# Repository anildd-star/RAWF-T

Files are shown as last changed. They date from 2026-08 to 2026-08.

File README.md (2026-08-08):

# RAF — Silah Organizörü

Three.js önizleme + **Elegoo Centauri Carbon 2** baskı kiti.

## Bugün baskı

1. [`print/BUGUN.md`](print/BUGUN.md) — adım adım  
2. Plakalar: [`print/plates/`](print/plates/) veya [`print/RAF-CC2-PLATES.3mf`](print/RAF-CC2-PLATES.3mf)  
3. **ELEGOO Slicer** → Centauri Carbon 2 → PETG → 5 mm brim → slice

Day-1: 2× panel + `plate_DAY1_minimum` → 2 silah asacak set.

## Tam dokümantasyon

[`print/PRINT_GUIDE.md`](print/PRINT_GUIDE.md)

```bash
python3 scripts/generate_print_kit.py
npx --yes serve .
```

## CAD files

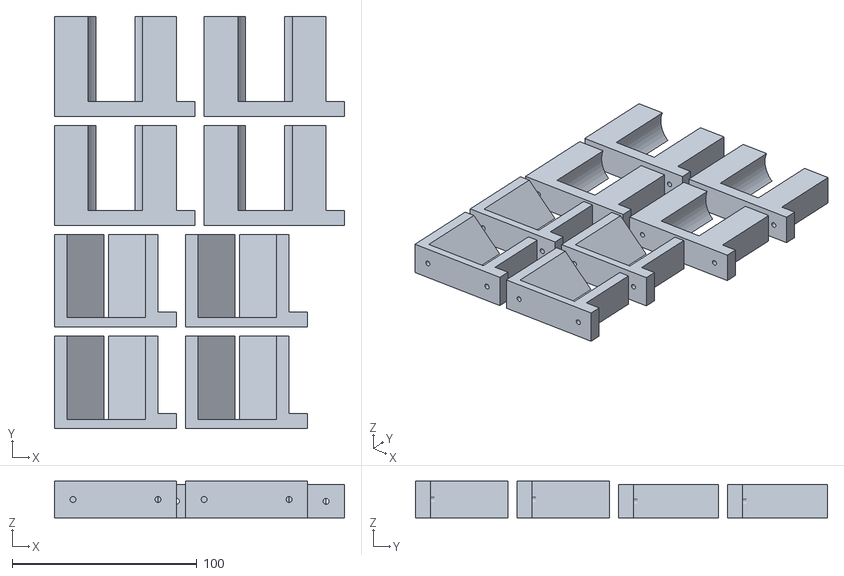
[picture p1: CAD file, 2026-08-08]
print/plates/plate_B_cradles_full.stl
157.0 x 223.0 x 20.0

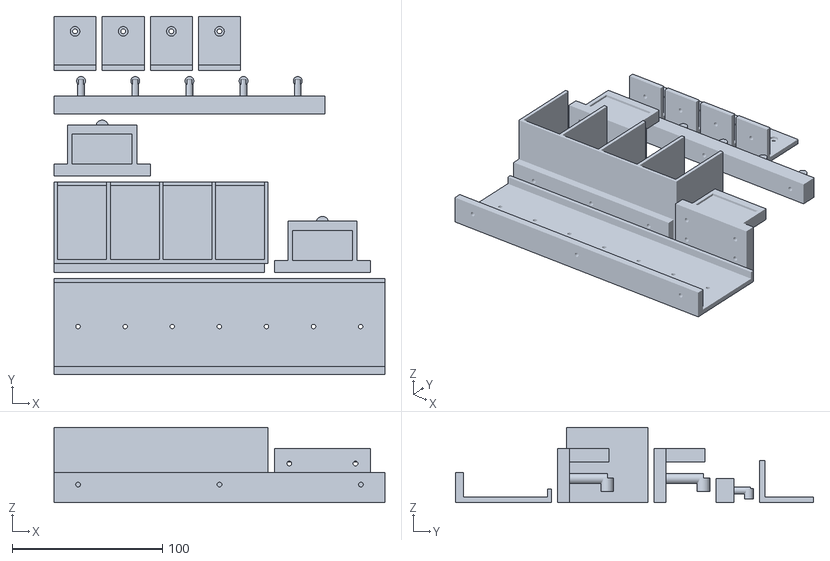
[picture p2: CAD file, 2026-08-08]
print/plates/plate_C_accessories.stl
220.0 x 238.2 x 50.0

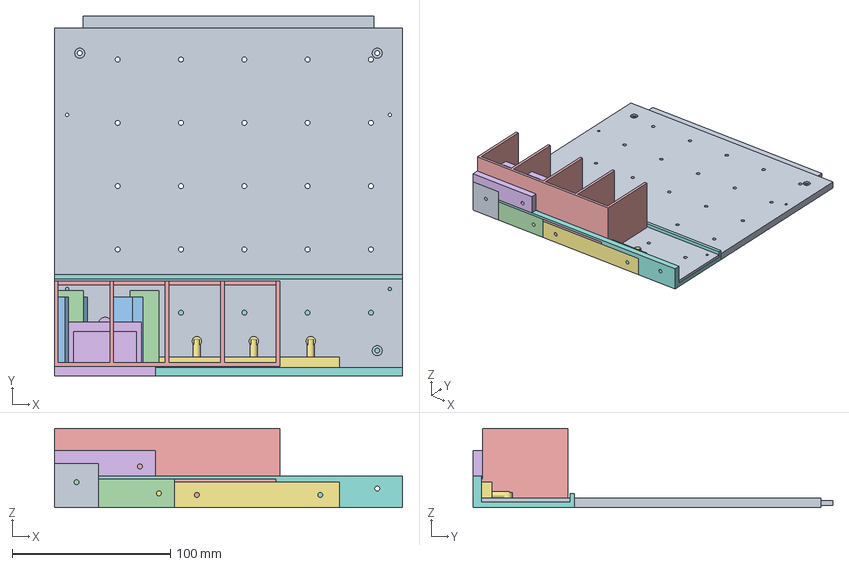
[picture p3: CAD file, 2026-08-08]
print/RAF-silah-organizoru-CC2.3mf
220.0 x 227.5 x 50.0 mm
01_back_panel
02_panel_pin
03_rifle_cradle
04_stock_rest
05_magazine_rack
06_pistol_mount
07_peg_rail
08_shelf
09_wall_bracket
10_tpu_felt_pad

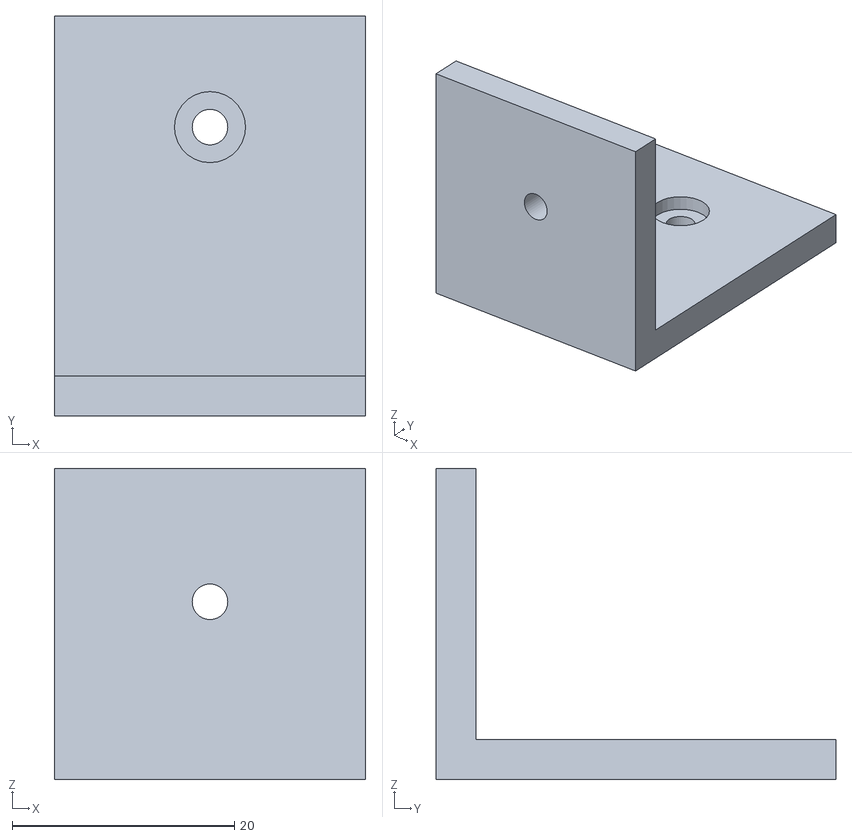
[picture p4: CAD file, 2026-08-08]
print/stl/09_wall_bracket.stl
28.0 x 36.0 x 28.0

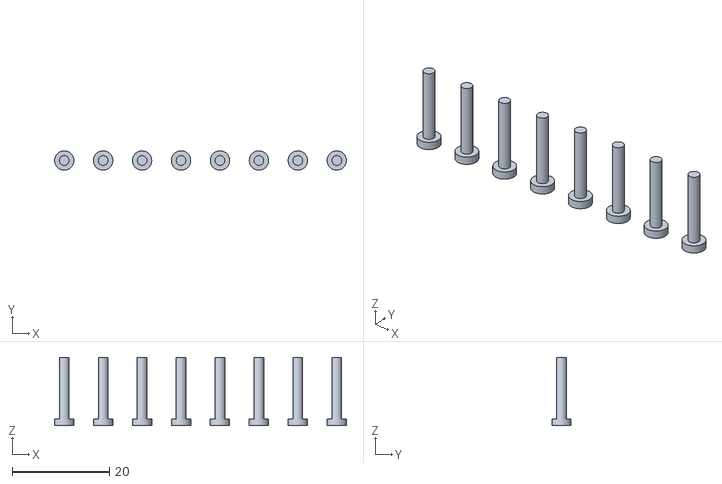
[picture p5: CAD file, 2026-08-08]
print/plates/plate_D_pins.stl
60.0 x 4.00 x 14.0

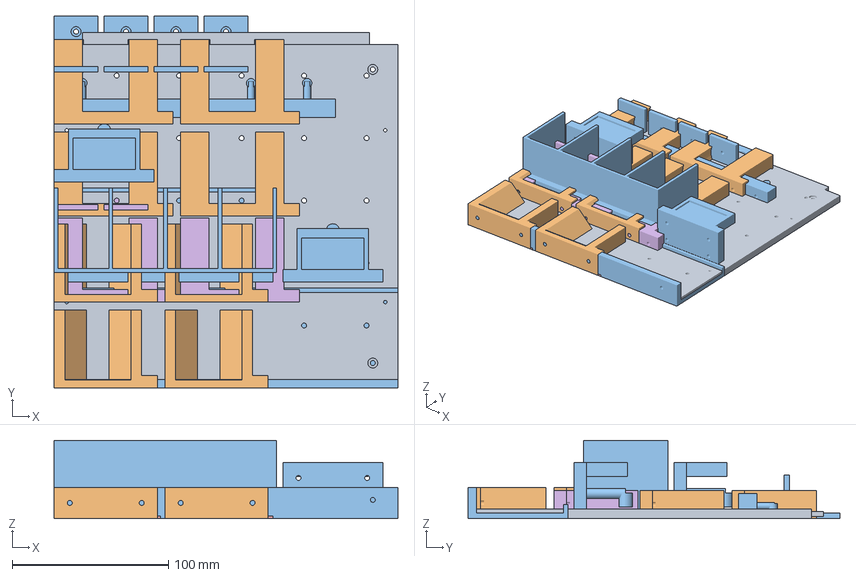
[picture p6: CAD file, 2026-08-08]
print/RAF-CC2-PLATES.3mf
220.0 x 238.2 x 50.0 mm
plate_A_panel_x1
plate_B_cradles_full
plate_C_accessories
plate_D_pins
plate_E_tpu_pads
plate_DAY1_minimum

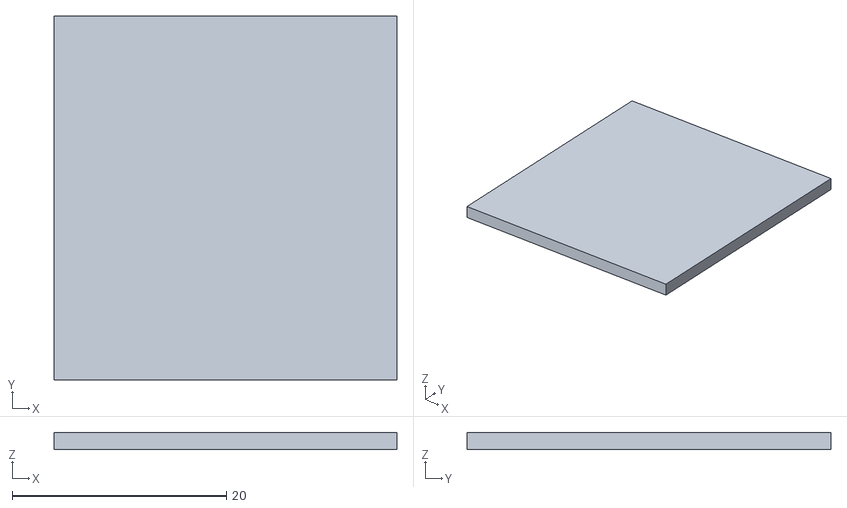
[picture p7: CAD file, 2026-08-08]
print/stl/10_tpu_felt_pad.stl
32.0 x 34.0 x 1.60

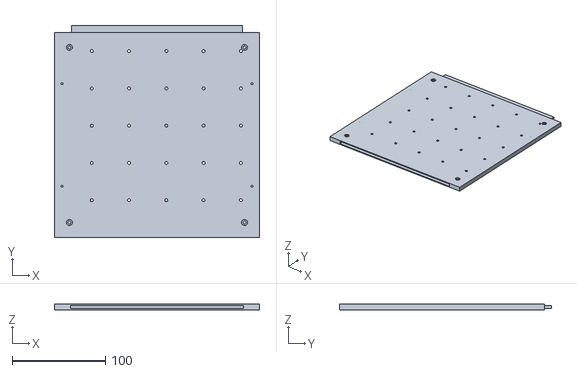
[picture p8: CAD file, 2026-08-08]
print/plates/plate_A_panel_x1.stl
220.0 x 227.5 x 6.00

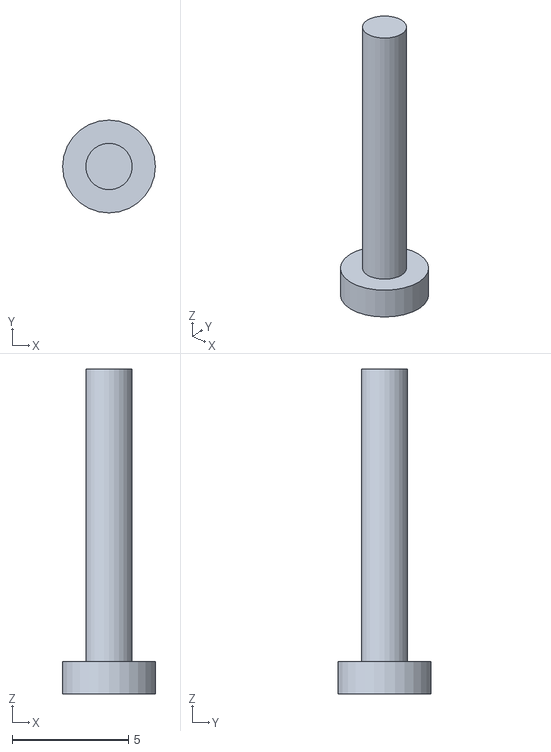
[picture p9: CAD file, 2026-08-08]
print/stl/02_panel_pin.stl
4.00 x 4.00 x 14.0

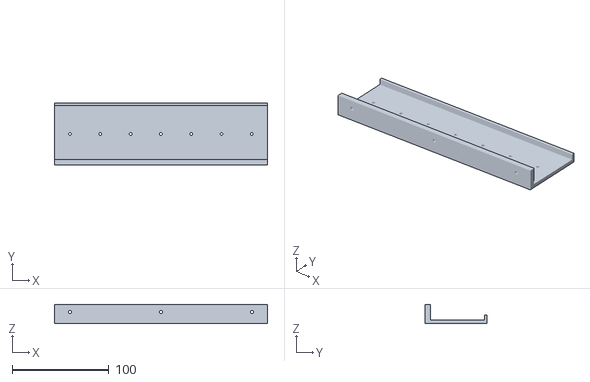
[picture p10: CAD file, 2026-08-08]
print/stl/08_shelf.stl
220.0 x 64.0 x 20.0

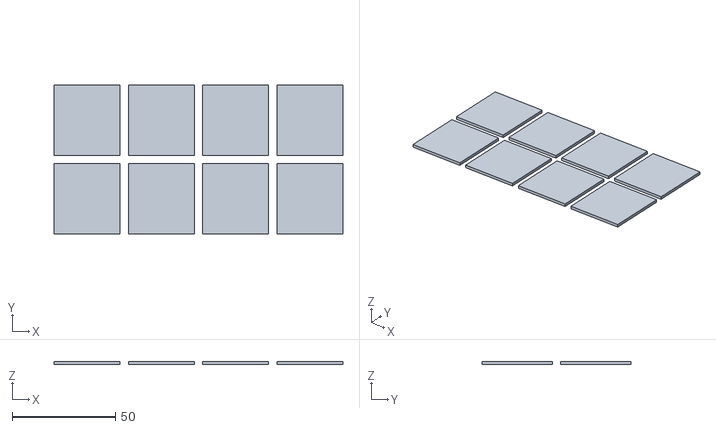
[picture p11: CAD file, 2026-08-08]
print/plates/plate_E_tpu_pads.stl
140.0 x 72.0 x 1.60

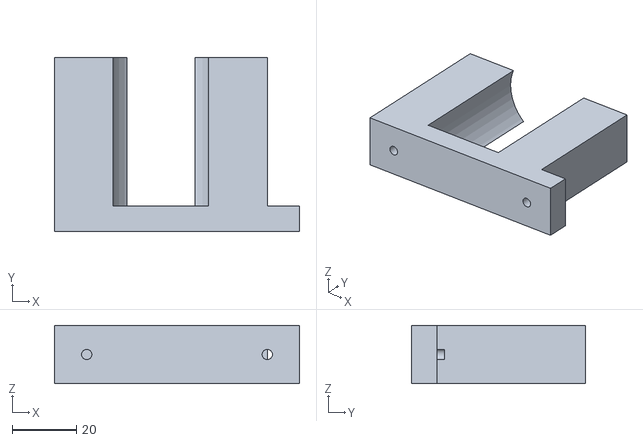
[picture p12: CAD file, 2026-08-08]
print/stl/04_stock_rest.stl
76.0 x 54.0 x 18.0

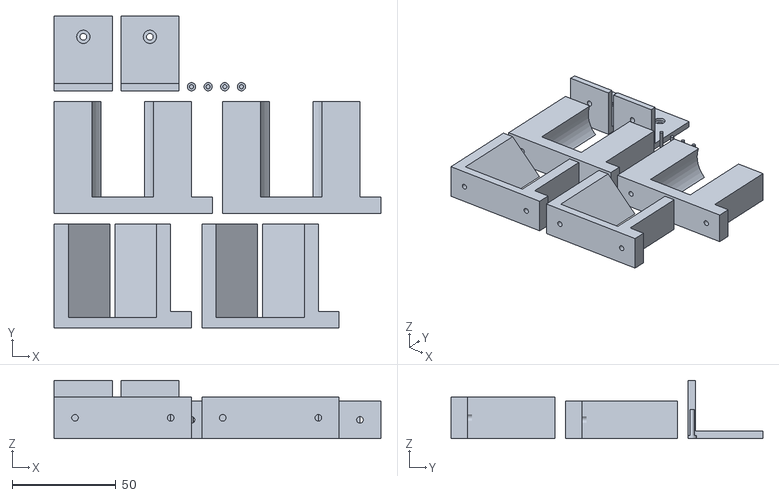
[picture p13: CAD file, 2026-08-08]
print/plates/plate_DAY1_minimum.stl
157.0 x 150.0 x 28.0

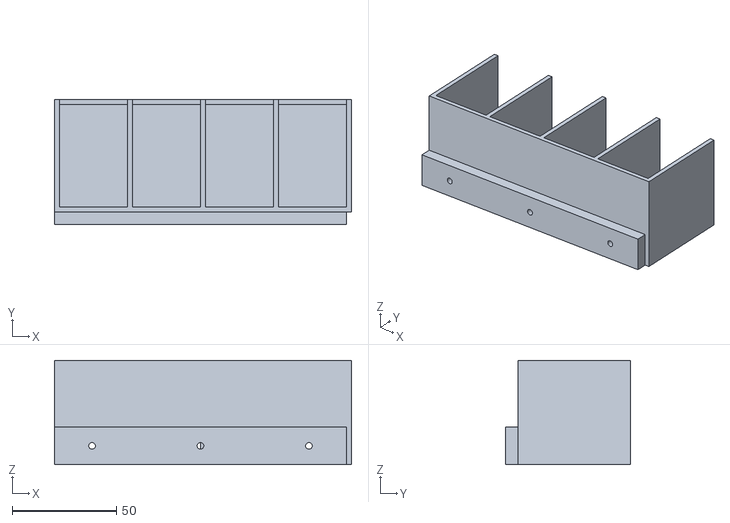
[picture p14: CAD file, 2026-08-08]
print/stl/05_magazine_rack.stl
142.4 x 60.0 x 50.0

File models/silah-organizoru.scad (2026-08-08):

// RAF Silah Organizörü — Centauri Carbon 2 (256³) uyumlu OpenSCAD
// Parçaları tek tek basmak için PART değişkenini değiştirin.
// Birimler: mm | Güvenli sınır: 250 mm

/* [Parça seçimi] */
// 0=panel 1=pin 2=cradle 3=stock 4=mag 5=pistol 6=peg 7=shelf 8=bracket 9=pad
PART = 0;

$fn = 48;
M3 = 3.2;

module m3_hole(h) cylinder(h = h, d = M3, center = true);

module back_panel() {
  w = 240; d = 240; t = 8;
  difference() {
    union() {
      cube([w, d, t]);
      // erkek kırlangıç
      translate([20, d, 2]) cube([w - 40, 9, 4]);
    }
    // dişi kanal
    translate([19, -0.2, 1.8]) cube([w - 38, 10.4, 4.4]);
    // montaj + ızgara
    for (x = [20:40:w-1])
      for (y = [20:40:d-1])
        translate([x, y, t/2]) m3_hole(t + 2);
    // hizalama
    for (y = [60, 180]) {
      translate([8, y, t/2]) cylinder(h = t + 2, d = 2.2, center = true);
      translate([w - 8, y, t/2]) cylinder(h = t + 2, d = 2.2, center = true);
    }
  }
}

module panel_pin() {
  cylinder(h = 16, d = 2);
  cylinder(h = 1.5, d = 4);
}

module rifle_cradle() {
  difference() {
    union() {
      translate([0, 4, 0]) cube([60, 46, 22]);
      cube([70, 8, 22]);
    }
    translate([30, 30, 22]) rotate([0, 45, 0]) cube([32, 55, 32], center = true);
    translate([12, 0, 11]) rotate([90, 0, 0]) m3_hole(20);
    translate([58, 0, 11]) rotate([90, 0, 0]) m3_hole(20);
  }
}

module stock_rest() {
  difference() {
    union() {
      translate([0, 4, 0]) cube([70, 51, 20]);
      cube([80, 8, 20]);
    }
    translate([35, 35, 14]) rotate([90, 0, 0]) cylinder(h = 50, r = 18, center = true);
    translate([12, 0, 10]) rotate([90, 0, 0]) m3_hole(20);
    translate([68, 0, 10]) rotate([90, 0, 0]) m3_hole(20);
  }
}

module magazine_rack() {
  w = 150; d = 58; h = 55; wall = 2.4;
  difference() {
    union() {
      cube([w, d, 3.2]);
      cube([w, wall, h]);
      for (i = [0:4]) translate([i * (w / 4), 0, 0]) cube([wall, d, h]);
      translate([0, d - wall, 0]) cube([w, wall, 8]);
      translate([0, -6, 0]) cube([w, 6, 20]);
    }
    for (x = [20, w/2, w - 20])
      translate([x, -3, 10]) rotate([90, 0, 0]) m3_hole(20);
  }
}

module pistol_mount() {
  difference() {
    union() {
      cube([70, 8, 40]);
      translate([10, 8, 30]) cube([50, 28, 10]);
      translate([35, 22, 18]) rotate([90, 0, 0]) cylinder(h = 28, r = 3.5, center = true);
      translate([35, 36, 10]) cylinder(h = 10, r = 4.5);
    }
    for (x = [12, 58]) for (z = [12, 28])
      translate([x, 0, z]) rotate([90, 0, 0]) m3_hole(20);
  }
}

module peg_rail() {
  w = 200; d = 14; h = 18;
  difference() {
    union() {
      cube([w, d, h]);
      for (i = [0:4]) {
        x = 20 + i * 40;
        translate([x, d + 8, h/2]) rotate([90, 0, 0]) cylinder(h = 22, r = 2.5, center = true);
        translate([x, d + 18, h/2 - 4]) cylinder(h = 8, r = 3.2);
      }
    }
    for (x = [15, w/2, w - 15])
      translate([x, d/2, h/2]) rotate([90, 0, 0]) m3_hole(30);
  }
}

module shelf() {
  w = 240; d = 70;
  difference() {
    union() {
      cube([w, d, 4]);
      translate([0, d - 3, 0]) cube([w, 3, 10]);
      translate([0, 0, 0]) cube([w, 6, 24]);
    }
    for (i = [0:6]) translate([20 + i * 33.3, d/2, 0]) cylinder(h = 5, d = 3.2);
    for (x = [20, w/2, w - 20])
      translate([x, 3, 14]) rotate([90, 0, 0]) m3_hole(20);
  }
}

module wall_bracket() {
  difference() {
    union() {
      cube([30, 40, 4]);
      cube([30, 4, 30]);
    }
    translate([15, 28, 0]) cylinder(h = 5, d = M3);
    translate([15, 2, 18]) rotate([90, 0, 0]) m3_hole(10);
  }
}

module felt_pad() cube([34, 38, 1.6]);

parts = [
  back_panel, panel_pin, rifle_cradle, stock_rest, magazine_rack,
  pistol_mount, peg_rail, shelf, wall_bracket, felt_pad
];

parts[PART]();

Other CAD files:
print/stl/07_peg_rail.stl
print/stl/06_pistol_mount.stl
print/stl/03_rifle_cradle.stl
print/stl/01_back_panel.stl

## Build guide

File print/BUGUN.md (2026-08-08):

# BUGÜN BASKI — Centauri Carbon 2

Tüm parçalar **256×256** yatağa **5 mm brim** ile sığar. G-code’u **ELEGOO Slicer** ile üret (CC2 profili).

## Şimdi yap (5 dk)

1. USB’ye kopyala:
   - `print/plates/plate_A_panel_x1.stl`
   - `print/plates/plate_DAY1_minimum.stl`
   - veya hepsi: `print/RAF-CC2-PLATES.3mf`
2. **ELEGOO Slicer** → Printer: **Centauri Carbon 2** → **0.20mm Standard**
3. Filament: **PETG** (yoksa PLA ile de basarsın ama yük taşımaz — sadece deneme)
4. Ayarlar (PETG):

| Ayar | Değer |
|---|---|
| Layer | 0.20 |
| Walls | 4 (yuvalarda 5) |
| Infill | %40 gyroid / panel %25 |
| Nozzle | 245 °C |
| Bed | 85 °C |
| Brim | **5 mm** |
| Supports | **Off** |
| Max speed | **180 mm/s** |

5. Slice → Export → yazıcıya gönder / USB kök dizinine at.

## Bugün sırası (2 silah asacak minimum)

| Sıra | Dosya | Adet baskı | Ne çıkar |
|---|---|---|---|
| 1 | `plate_A_panel_x1.stl` | **2 kez** | 2 arka panel (~440 mm yükseklik) |
| 2 | `plate_DAY1_minimum.stl` | **1 kez** | 2 yuva + 2 dayanak + 2 braket + 4 pin |

Tahmini PETG: **~0.9–1.1 kg** (infill’e göre). Tek makaraysa önce 1 panel + DAY1 bas, ikinci paneli sonra.

## Tam kit (sonraki oturumlar)

| Plaka | Dosya | Not |
|---|---|-----|
| A | `plate_A_panel_x1.stl` | Toplam **3** panel |
| B | `plate_B_cradles_full.stl` | 4+4 yuva |
| C | `plate_C_accessories.stl` | raf, şarjör, tabanca, askı, braket |
| D | `plate_D_pins.stl` | pinler |
| E | `plate_E_tpu_pads.stl` | **TPU** ile bas |

Tekil STL: `print/stl/`  
Ayar JSON: `print/cc2-settings.json`

## Montaj (bugün bitince)

1. 2 paneli kırlangıç + pin ile birleştir  
2. 2 braket ile duvara sabitle (sağlam dübel)  
3. Üste 2 cradle, alta 2 stock_rest (aynı hiza)  
4. Silahı asmadan önce yuva içine keçe/TPU veya elektrik bandı koy  

## Dikkat

- Brim açık kalsın; panel büyük yüzey, warp riski var.  
- Glue stick / temiz PEI kullan.  
- Orca’dan G-code atma; **ElegooSlicer CC2** profili kullan (`PRINT_START` / `PRINT_END`).  
- 500 mm/s kullanma — fonksiyonel parça.

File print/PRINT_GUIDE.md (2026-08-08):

# Elegoo Centauri Carbon 2 — Baskı Kılavuzu

> **Bugün basıyorsan:** önce [`BUGUN.md`](BUGUN.md) oku.

Yatak **256 × 256 × 256 mm**. Parçalar brim (5 mm) ile **≤244 mm** olacak şekilde boyutlandırıldı.

## Dosyalar

| Dosya | Kullanım |
|---|---|
| [`BUGUN.md`](BUGUN.md) | Bugünkü adım adım sıra |
| [`plates/`](plates/) | Hazır dizilmiş plakalar (önerilen) |
| [`RAF-CC2-PLATES.3mf`](RAF-CC2-PLATES.3mf) | Tüm plakalar tek 3MF |
| [`stl/`](stl/) | Tek parçalar |
| [`RAF-silah-organizoru-CC2.3mf`](RAF-silah-organizoru-CC2.3mf) | Tek parçalar 3MF |
| [`cc2-settings.json`](cc2-settings.json) | Slicer parametreleri |
| [`manifest.json`](manifest.json) | Boyut / filament tahmini |

## Slicer

**ELEGOO Slicer** → makine: **Centauri Carbon 2** → **0.20mm Standard**  
G-code’u Orca’dan üretme; CC2 `PRINT_START` / `PRINT_END` makroları Elegoo profilinde.

## Malzeme

| Parça | Filament |
|---|---|
| Panel, yuva, raf, braket, pin | **PETG** veya PETG-CF |
| `plate_E_tpu_pads` | **TPU 95A** |

## Adet (tam kit)

| Parça | Adet |
|---|---|
| back_panel | 3 (~660 mm yükseklik) |
| rifle_cradle | 4 |
| stock_rest | 4 |
| magazine_rack | 1 |
| pistol_mount | 2 |
| peg_rail | 1 |
| shelf | 1 |
| wall_bracket | 4 |
| panel_pin | 8 |
| tpu_felt_pad | 8 |

Donanım: M3×12 ≈ 36, M3×16 ≈ 8, duvar dübeli.

## PETG ayar (0.4 mm)

Layer 0.20 · Walls 4 (yuva 5) · Infill %40 gyroid (panel %25) · 245 / 85 °C · Fan %40 · Brim 5 mm · Supports off · Max 180 mm/s

## Plaka planı

1. `plate_A_panel_x1` ×3  
2. `plate_B_cradles_full` ×1  
3. `plate_C_accessories` ×1  
4. `plate_D_pins` ×1  
5. `plate_E_tpu_pads` ×1 (TPU)

## Yeniden üret

```bash
pip install trimesh manifold3d numpy
python3 scripts/generate_print_kit.py
```

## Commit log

2026-08-08 Add interactive 3D gun organizer model (Three.js + OpenSCAD) (#1)
    Wall-mounted oak/steel firearm organizer with rifle cradles, pistol
    mounts, magazine rack, accessory shelf, and peg strip. Includes
    OrbitControls viewer and parametric OpenSCAD source for printing.
    [silah-organizoru.scad]
2026-08-08 Prepare modular Centauri Carbon 2 print kit (256³)
    Split organizer into 10 printable parts all ≤250 mm. Export STL + 3MF,
    BOM, PETG/TPU slice settings, and Turkish print/assembly guide for
    Elegoo Centauri Carbon 2 (0.4 mm nozzle).
    [01_back_panel.stl, 02_panel_pin.stl, 03_rifle_cradle.stl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]
2026-08-08 CC2 same-day print plates: brim-safe sizes + DAY1 kit
    Shrink parts to fit 256 bed with 5 mm brim, add packed plates A–E,
    DAY1 minimum set for 2 guns, and BUGUN.md checklist for Elegoo Slicer.
    [02_panel_pin.stl, 03_rifle_cradle.stl, 04_stock_rest.stl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]
